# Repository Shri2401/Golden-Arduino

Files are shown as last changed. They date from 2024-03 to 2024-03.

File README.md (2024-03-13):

# Golden-Arduino
## Aim:
The project targets the creation of a standalone 4-layer instrument droid(Arduino base) focusing on:

- Utilizing a 328 microcontroller and data acquisition system.
- Prioritizing non-compatibility with Arduino Uno R3.
- Ensuring access to essential pins for bootloading.
- Emphasizing proficiency in 4-layer design.
- Measuring and characterizing the output impedance of diverse voltage sources, including dynamic Thevenin resistance.
- Providing thorough documentation focusing on design, assembly, testing, and code development.

## POR (Plan of Record):
The Plan of Record (POR) outlines various features and requirements of the project, including:

- Incorporating a power plug for an external 5V AC to DC charger.
- Implementing a voltage regulator for efficient operation of components.
- Including USB mini support for programming and powering the board.
- Integrating a power selector switch to choose between USB and external power supply.
- Utilizing a Low Drop-Out (LDO) regulator for stable 3.3V.
- Installing indicator LEDs for visual confirmation of power status.
- Implementing a power isolator switch and reset switch.
- Ensuring compatibility for bootloading and programming.
- Developing functionality to measure in-rush current and protect against static voltage damage.
- Providing extra headers for convenient ground connections.
- Planning test points for critical signals.
- Placing decoupling capacitors and implementing a copper poured ground plane.

## Risk Reduction Steps:
To mitigate risks associated with the project, various steps have been taken, including:

- Thorough research and validation of components.
- Prototyping and simulating critical sections of the board design.
- Performing comprehensive analysis of the board layout.
- Conducting in-depth testing of each feature.
- Implementing feedback mechanisms and standardizing signal lines.

## Demonstration Goals:
The demonstration goals include bootloading the Atmega 328, maintaining compatibility with standard header pin footprints, achieving noise levels lower than commercial boards, and more.

## Expectations of "Work":
Expectations include reliable power-up, efficient voltage regulation, accurate current measurement, smooth bootloading processes, and effective noise reduction measures.

## Significant Parts Used:
Significant parts used in the project include ATMEGA328, LDO (AMS1117), CH340g, Crystal Oscillators, DAC MCP4725, ADC ADS111x, and OP-AMP MCP6002.

##  Design:
Various visuals and diagrams are provided to illustrate the project's design, layout, and assembly process.
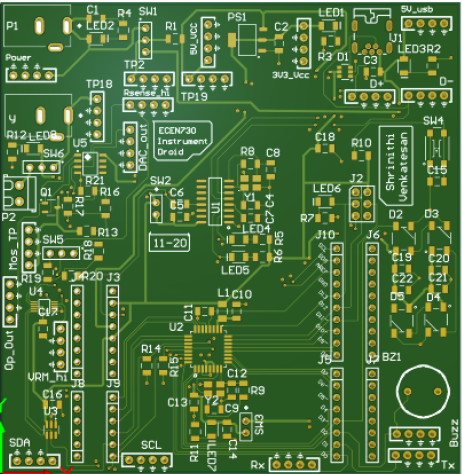
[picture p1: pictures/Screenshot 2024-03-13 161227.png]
Schematic

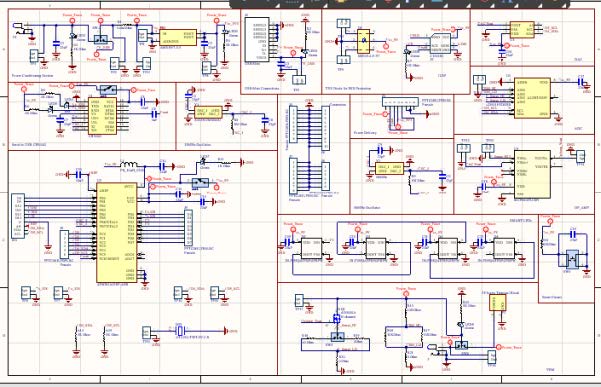
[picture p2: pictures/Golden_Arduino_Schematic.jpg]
Bare Board

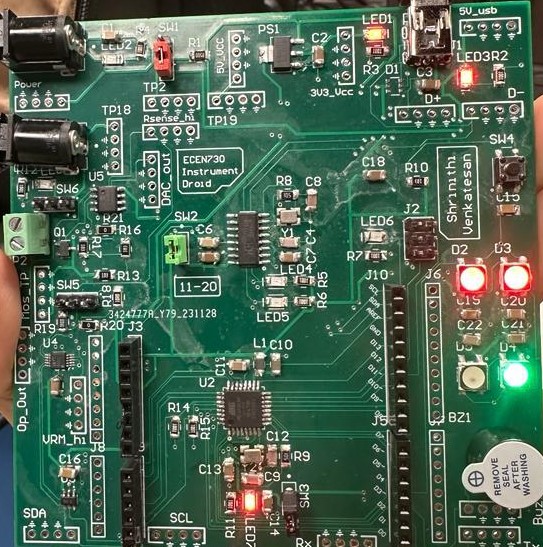
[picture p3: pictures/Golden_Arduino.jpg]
PCB


## Bring-Up Process Summary:
The bring-up process involved short testing of the bare board, precise component placement, soldering, testing, bootloading, and code execution.

## Learning Outcomes
Through the process of developing the circuit design and implementing strategic routing techniques, several valuable learning outcomes have been achieved:

1. Thorough Circuit Design: By deeply understanding and incorporating insights from available references, this project has emphasized the importance of meticulous circuit design. Prioritizing best design practices and optimizing layout have been essential steps in ensuring precision and reliability.

2. Signal Integrity Management: Employing strategic routing techniques and grounding practices has enabled the mitigation of potential signal integrity issues. Understanding the impact of layout and routing on signal quality has been crucial in optimizing performance.

3. Noise Resistance Improvement: Implementing best routing techniques and measures has led to better noise resistance compared to previous designs. By carefully considering the placement of components and utilizing techniques such as ferrite beads, noise interference has been minimized, resulting in improved overall performance.

4. Anticipating Expected Outcomes: Learning to anticipate the expected outcome based on design decisions and implementation choices has been a central aspect of this project. Understanding the role of each component and technique in achieving specific project goals has been essential in maintaining a systematic approach to circuit design and testing.

In conclusion, by incorporating these best practices and maintaining a systematic approach to circuit design and testing, the reliability and success of future projects can be greatly enhanced. Learning from both successes and challenges encountered during this project will contribute to further improvements and best implementations in future endeavors.

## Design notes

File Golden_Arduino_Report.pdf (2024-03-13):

ECEN 4730-5730-001 | Practical PCB Design Manufacture | Fall 2023
| Board4 Report
| Shrinithi Venkatesan

Aim:

The project targets a standalone 4-layer instrument droid for graduate students, featuring a 328 microcontroller and data acquisition system. It prioritizes non-compatibility with Arduino Uno R3 but ensures access to essential pins for bootloading. Emphasizing 4-layer design proficiency, the instrument measures and characterizes the output impedance of diverse voltage sources, including dynamic Thevenin resistance. Underpinned by insights from Lab 21, the solderless breadboard version, the process involves meticulous assembly, bootloading, and rigorous testing. Thorough documentation focuses on design, assembly, testing, and code development, enhancing the graduate educational experience in board design and microcontroller programming.

POR:

1. Incorporate a power plug for an external 5V AC to DC charger to power the board.
2. Implement a voltage regulator to convert 5V to 3.3V for efficient operation of components.
3. Include USB mini support for programming and powering the board.
4. Integrate a power selector switch to choose between USB and the 5V external power supply.
5. Utilize a Low Drop-Out (LDO) regulator to convert 5V to stable 3.3V.
6. Install indicator LEDs for visual confirmation of 5V and 3.3V power status.
7. Implement a power isolator switch to disconnect power to the microcontroller and CH340 chip.
8. Include a reset switch to initiate a reset of the microcontroller in case of undesired behavior.
9. Ensure In-Circuit Serial Programming (ICSP) compatibility for bootloading and programming the microcontroller.
10. Develop functionality to measure in-rush current during board startup.
11. Add Transient Voltage Suppression (TVS) chip to protect against static voltage damage.
12. Provide extra headers for convenient ground connections for sensors or other peripherals.
13. Plan test points for critical signals:
5V input
3.3V input
In-rush current measurement USB D+ and D-USB VBUS
Microcontroller RX and TX
Microcontroller SDA and SCL
14. Place decoupling capacitors in proximity to all ICs to reduce switching noise.

15. Implement a copper poured ground plane for effective signal return and noise reduction.
16. Implement an ADC to accurately measure the differential voltage between the sense resistor and the VRM.
17. Utilize the DAC output to drive the MOSFET through an Op-Amp, establishing a current source system.
18. Establish connections for smart LEDs and a buzzer to the digital pins of the ATmega328.

Risk Reduction Steps:

1. Thoroughly research and validate the chosen components for reliability and compatibility.
2. Prototype and simulate critical sections of the board design to identify and mitigate potential issues.
3. Perform a comprehensive analysis of the board layout to ensure proper signal integrity.
4. Conduct in-depth testing of each feature to validate its functionality and performance.
5. Implement feedback mechanisms to monitor and address potential problems during the testing phase.
6. Standardizing signal lines to 6 mils width and power lines to 20 mils width is a sound practice. This design decision simplifies the detection of signal and power nets, reducing the risk of misconnection or interference.
7. Keeping board size under 3.9” to ensure it sticks to standards.
8. Adhering to established best practices by using as many ground VIAs to ensure there’s no noise due to return currents in the ground plane. Placing decoupling capacitors closer to IC.
9. By placing test points and appropriately labeling them, you mitigate the risk of confusion during testing and debugging. This practice ensures that you can easily access critical points for measurement and verification.
10. Using switches at each stage for isolation and debugging purposes is a proactive measure to minimize risks. These switches allow you to control and isolate specific sections of the circuit, making it easier to identify and address issues without affecting the entire system.

Demonstration Goals:

1. Bootload the Atmega 328 to turn it into an Arduino.
2. Run the Arduino IDE and execute a standard sketch on the board.
3. Maintain compatibility with standard header pin footprints for shields.
4. Achieve noise levels 20% to 50% of a commercial board under identical conditions.
5. Ensure near-field emissions are less than 10% of a commercial Arduino board.
6. Optionally, add test points for digital buses to observe actual bus traffic.
7. Optionally, measure in-rush current and steady-state current with a series resistor for current sensing.

Expectations of what it is to “work”:

1. The board should reliably power up from both USB and a 5V external supply, ensuring consistent and stable operation.

2. The power indicator LED must promptly illuminate upon the application of power, providing a clear visual cue.
3. The voltage regulator should consistently and efficiently convert the 5V input to a stable and accurate 3.3V output.
4. The board should accurately measure the current flowing through one of the LEDs, providing a reliable metric for analysis.
5. SPI communication must function reliably to facilitate successful bootloading processes.
6. The board, configured as a Golden Arduino, should seamlessly execute any standard Arduino sketch, ensuring broad compatibility.
7. Indicator switches and lights should respond promptly to user inputs, enhancing the user interface and feedback mechanisms.
8. The reset signal should effectively reset the ATmega328, contributing to the stability of the microcontroller.
9. Bootloading processes should be smooth and compatible with various Arduino programmers, ensuring versatility in development environments.
10. Inrush current measurement, conducted using the scope, should provide accurate and meaningful results, allowing for comprehensive analysis.
11. The Low Drop-Out (LDO) regulator should consistently provide a steady 3.3V output without oscillations or instability.
12. Implemented design measures should result in a noticeable reduction in near-field emissions, contributing to electromagnetic compatibility.
13. Observing RX and TX waveforms during code loading should be clear and consistent, allowing for effective monitoring and analysis.
14. The board should demonstrate noise levels 20% to 50% lower than those observed in commercial Arduino boards, showcasing effective noise reduction measures.
15. The DAC ensures the accurate generation of voltage and waveform in accordance with the programmed code.
16. The instrument droid is equipped to conduct measurements, utilizing any external power source connected to the board's venin voltage and resistance.
17. The reset signal performs as anticipated, effectively resetting the ATmega328 when triggered

Significant Parts used:

1. ATMEGA328- https://www.microchip.com/en-us/product/atmega328p
2. LDO - AMS1117 - http://www.advanced-monolithic.com/pdf/ds1117.pdf
3. CH340g - 74AHC14
-https://cdn.sparkfun.com/datasheets/Dev/Arduino/Other/CH340DS1.PDF
4. Crystal Oscillators - 16,12Mhz
5. DAC MCP4725 https://ww1.microchip.com/downloads/en/devicedoc/22039d.pdf
6. ADC ADS111x https://www.ti.com/lit/ds/symlink/ads1114.pdf
7. OP-AMP MCP6002 https://www.microchip.com/en-us/product/mcp6002

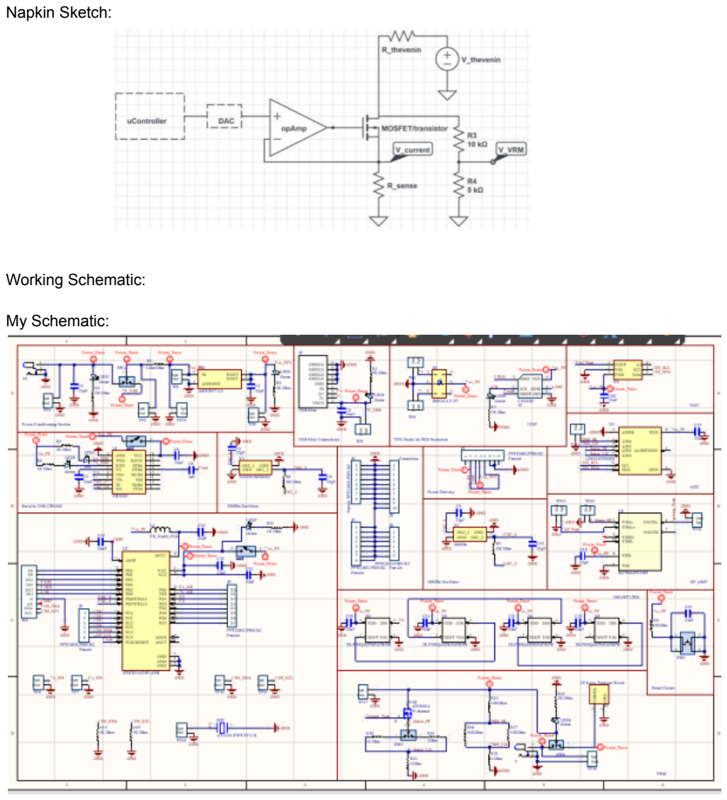
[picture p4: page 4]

Napkin Sketch:

Working Schematic:

My Schematic:

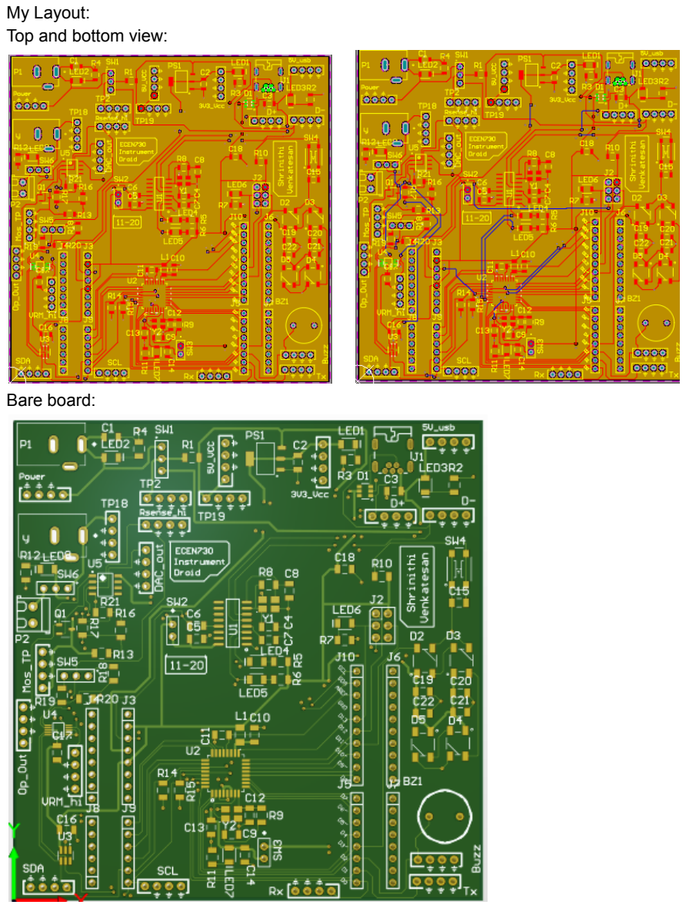
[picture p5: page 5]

My Layout:
Top and bottom view:

Bare board:

Assembled Board:

Power on design
Power plug and CH340

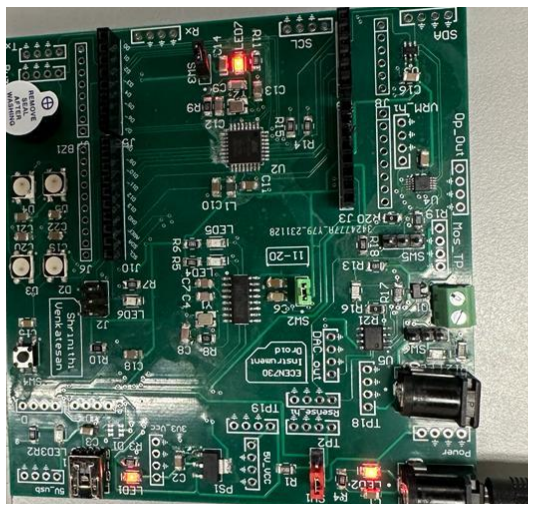
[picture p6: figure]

Bring-up Process Summary:

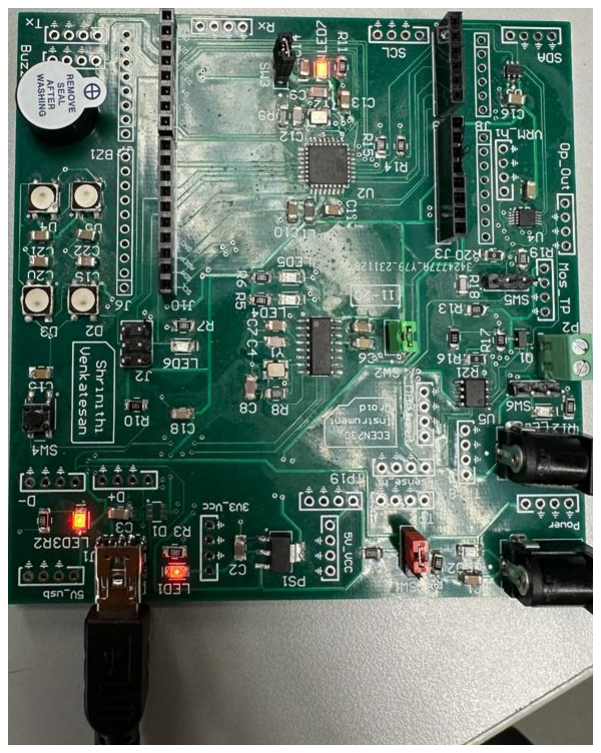
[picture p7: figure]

1. Conducted a short test on the bare board to verify the integrity of all connections and ensure proper functionality.
2. Placed all components, utilizing 1206 components, and ensured precise positioning before soldering.
3. Soldered the components with precision, followed by another round of short testing to identify and rectify any accidental shorts caused during soldering.Detected a short and tried to hard correct it by scratching out the trace, yet not successful.
4. 5V and LDO output was proper and verified.
5. Attempted to boot-load the controller using a commercial Arduino by just soldering the required components for that.
6. After that the blink code was dumped to verify communication with the controller working as expected.

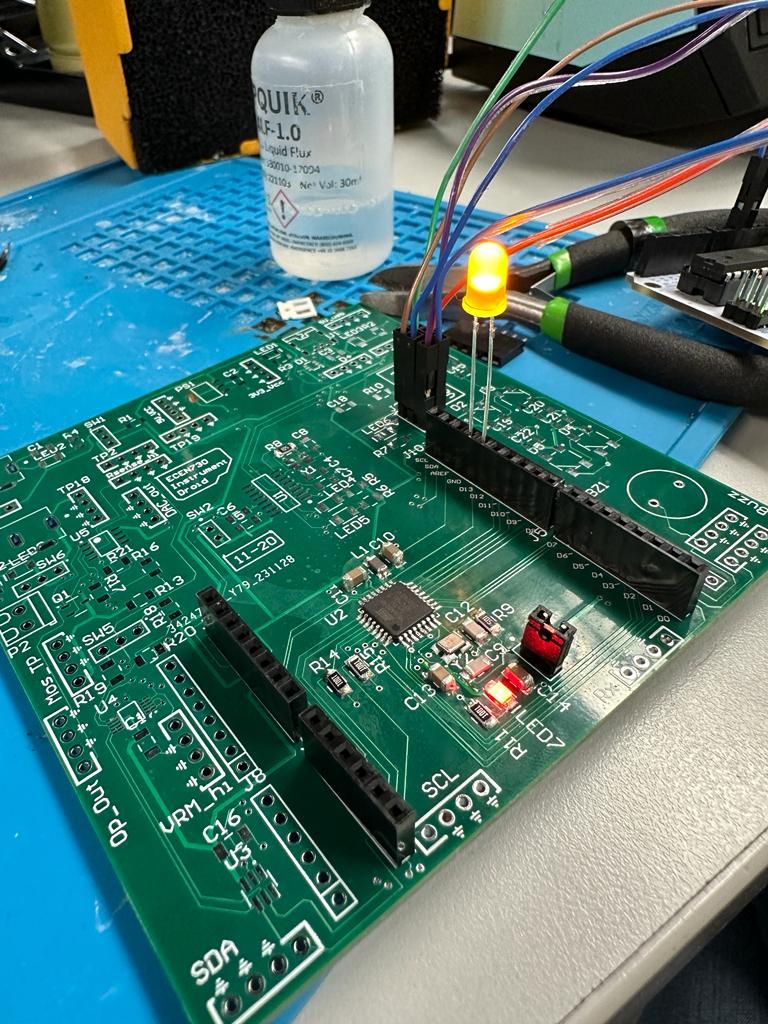
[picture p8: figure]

Measurements and Analysis:

Power rail outputs:

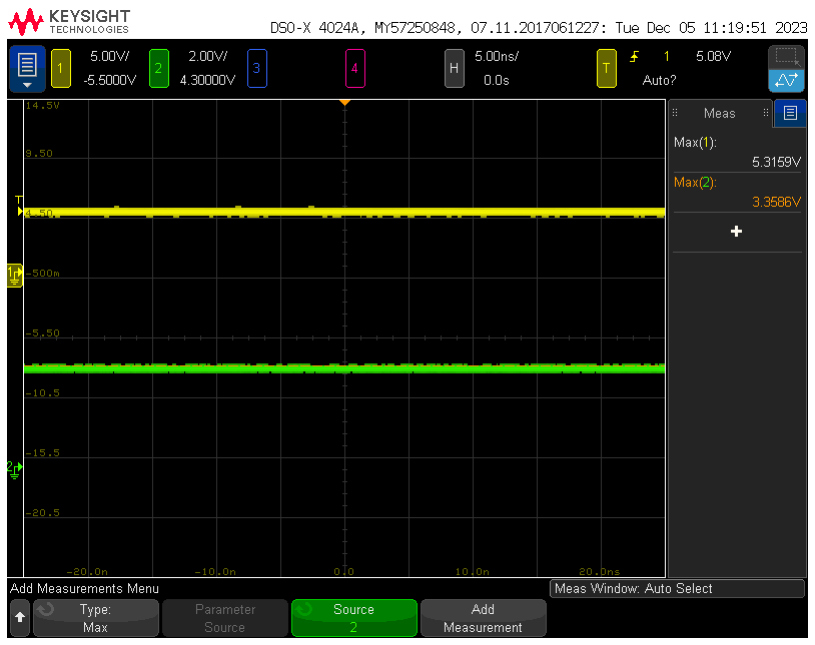
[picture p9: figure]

The observed voltages align closely with the expected values, with 5.3V and 3.3V measured at the 5V and 3.3V test points, respectively. The corresponding LEDs for both voltage rails have illuminated, indicating that the power supply and voltage regulation systems are functioning as intended.

The oscilloscope channel readings further validate the stability of the voltage rails. Channel 1 (Yellow) displays a consistent 3.3V, confirming the proper operation of the 3.3V rail. Similarly, Channel 2 (Green) shows a steady 5V, validating the performance of the 5V rail.

These results demonstrate the successful power supply and voltage regulation aspects of the board, providing a solid foundation for further testing and functionality verification.

Oscillator Outputs:

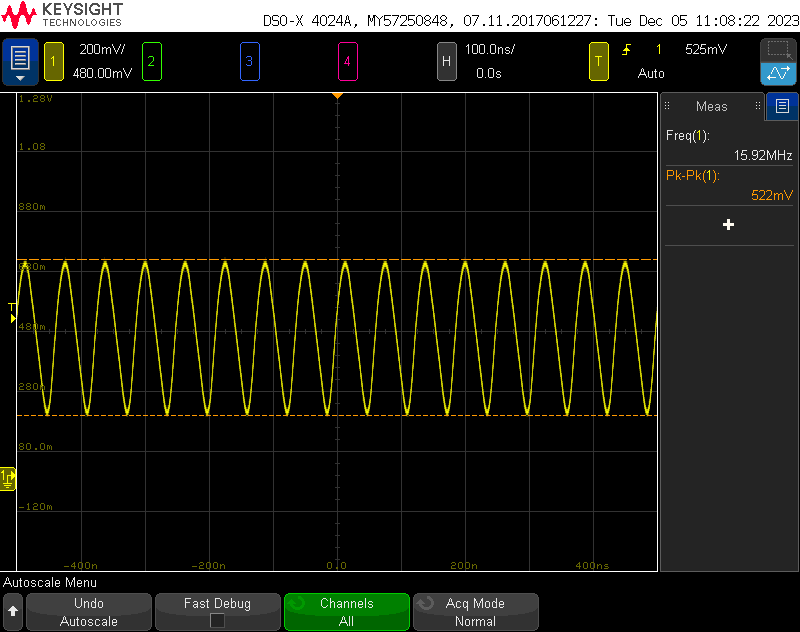
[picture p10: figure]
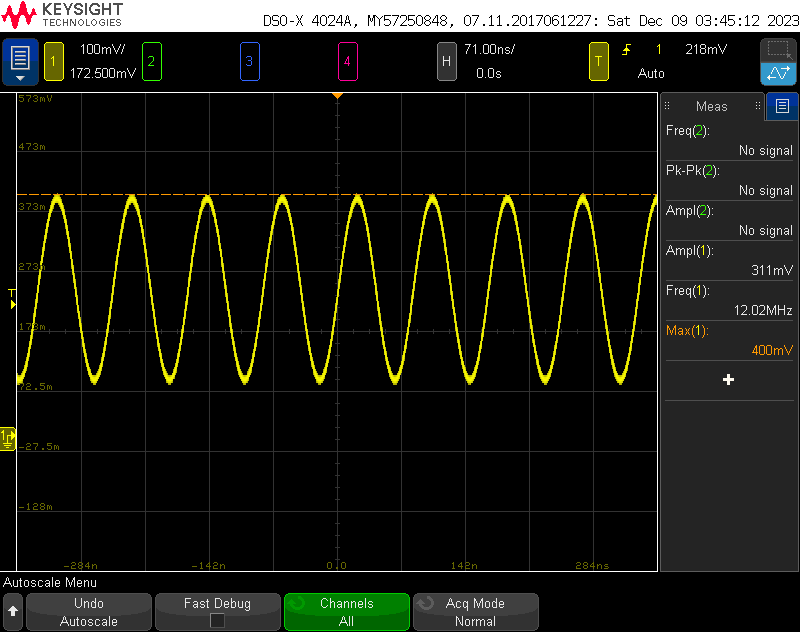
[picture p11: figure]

12Mhz from Y1 | 16Mhz from Y1

The presence of a 16MHz clock signal for the microcontroller indicates that the ATmega328 or a similar microcontroller is operating at the expected frequency. The presence of a 12MHz clock signal for the CH340G indicates that the USB-to-serial converter is functioning with the expected clock frequency.

Data Signals: D+ and D-:

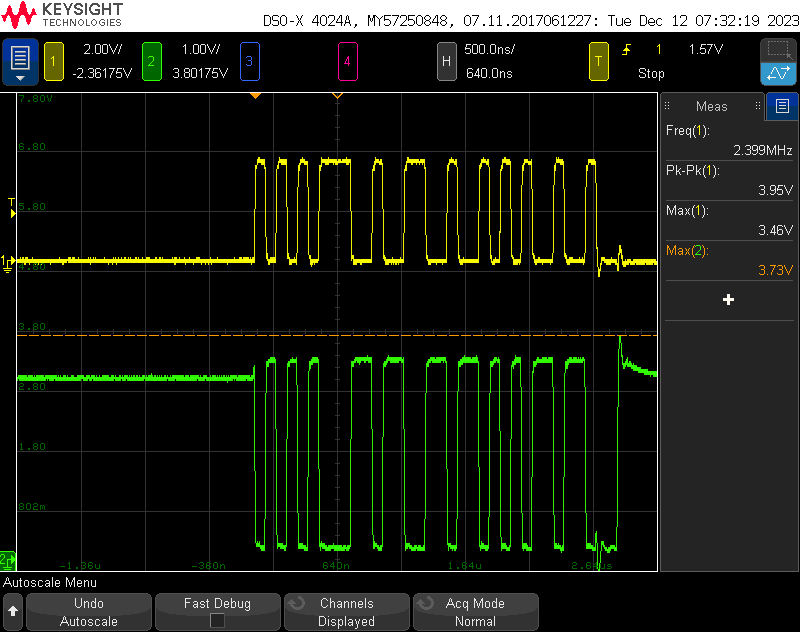
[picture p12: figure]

The presence of both the D+ (yellow trace) and D- (green trace) signals, specifically when the board is powered by a mini-USB cable and a USB port is detected, verifies the correct connection and functionality of the CH340G chip. These differential signals carry the data and inverted data signals, and their successful observation under the specified conditions indicates the proper operation of the USB communication interface.

The detection of a USB port serves as a positive confirmation that the D+ and D- signals are correctly connected. This validation is crucial for ensuring the reliable communication and functionality of the USB interface on the board.

Rx and Tx signals:

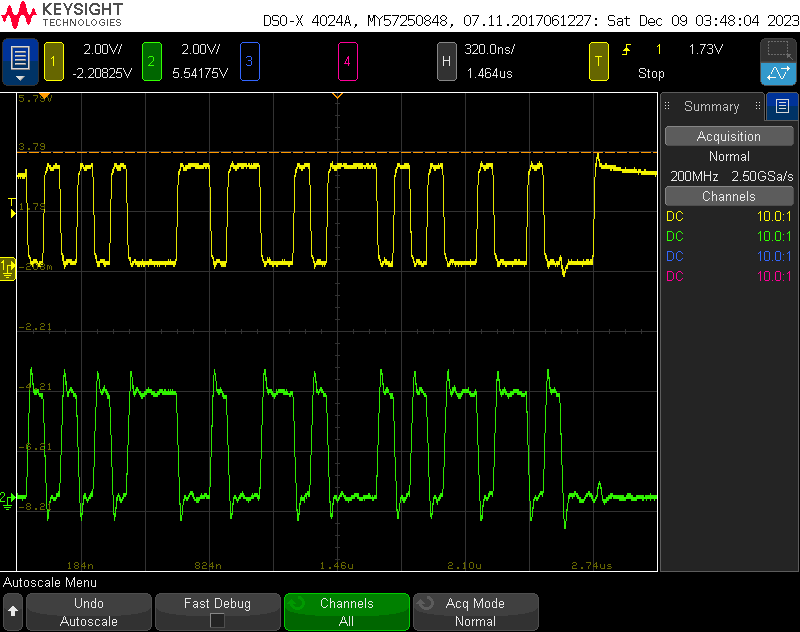
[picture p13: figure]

The observed UART Rx (yellow trace) and UART Tx (green trace) waveforms confirm the interaction between the ATmega328 microcontroller and the CH340G during the code uploading process through USB. The blinking of the Rx and Tx LEDs during code upload indicates the successful communication between the microcontroller and the USB interface.

The triggering of the signals on the falling edge, as mentioned, aligns with UART communication standards where a 0 bit is used as the start bit. This behavior is consistent with proper UART communication protocols.

These results validate the functional interaction between the microcontroller and the USB interface, ensuring the successful upload of code to the ATmega328. The observed waveforms provide valuable insights into the communication dynamics and help verify the integrity of the UART interface on the board.

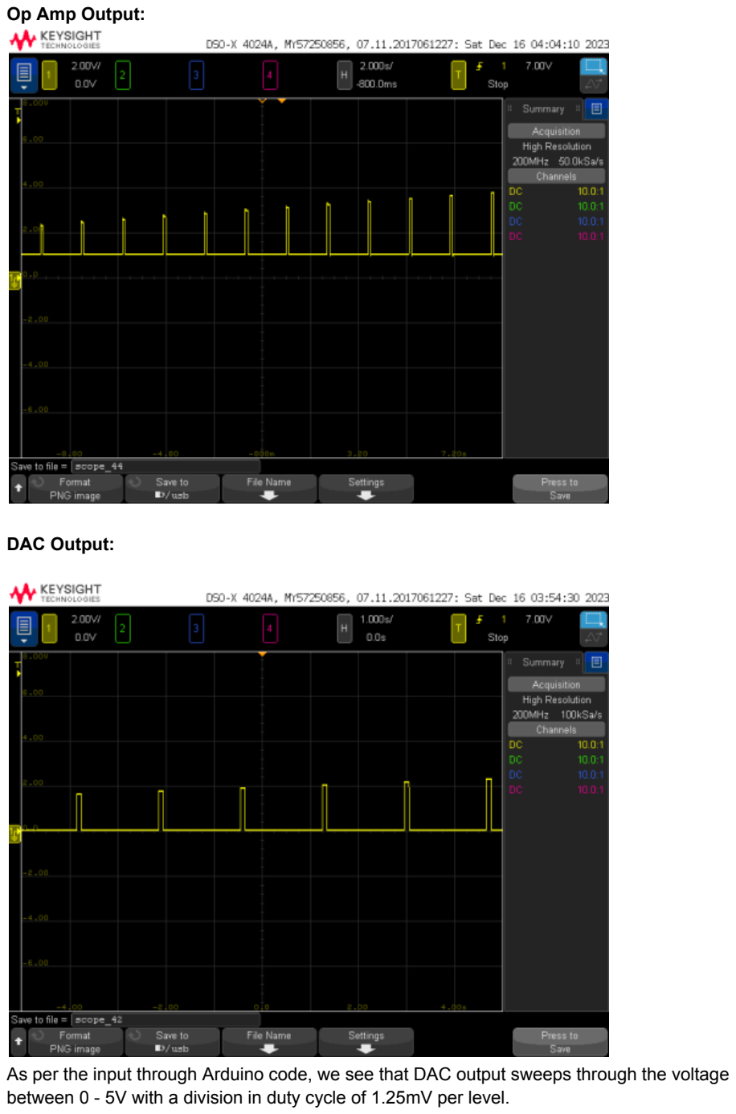
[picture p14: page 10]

Op Amp Output:

DAC Output:

As per the input through Arduino code, we see that DAC output sweeps through the voltage between 0 - 5V with a division in duty cycle of 1.25mV per level.

Power source characteristics:
As a known source, we apply an input of 5V, 9V and 2A through the source and plot our respective outputs through the circuit. We observe expected outputs when using 10ohm sense resistor value.

9V 2A
Index, current in mA, V_thevenin, V_loaded, R_thevenin

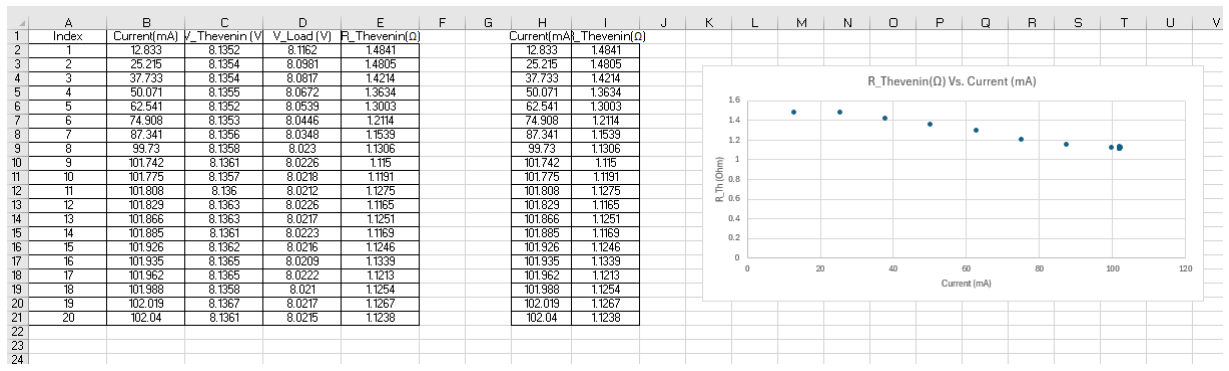
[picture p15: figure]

The yellow trace here is the Rth plot

5V 2A
Index, current in mA, V_thevenin, V_loaded, R_thevenin

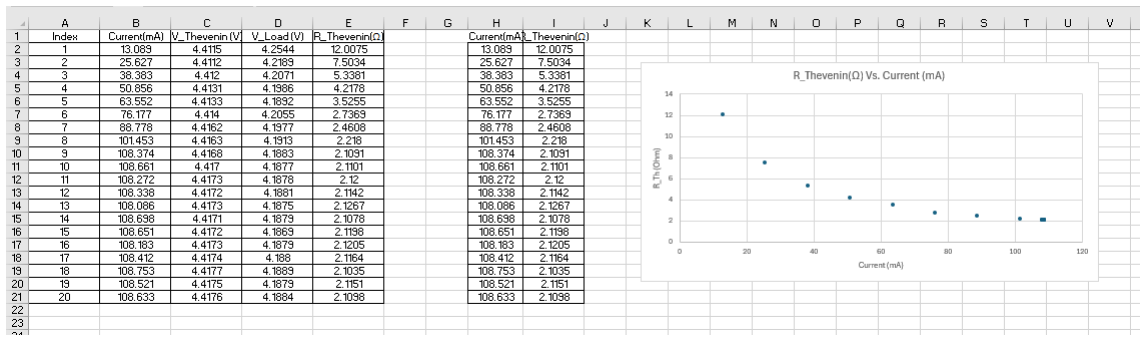
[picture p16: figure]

Here, I have compared the values between Current(blue) vs Rth(yellow)

5V 1A (bench power gen)
Through the function generator we provide input of 5V 1A and observe the following output as expected values. We first experimented with unknown values of VRM using a variety of sense resistor values from 1 Ohm and finally used 10 Ohm to observe the following output.

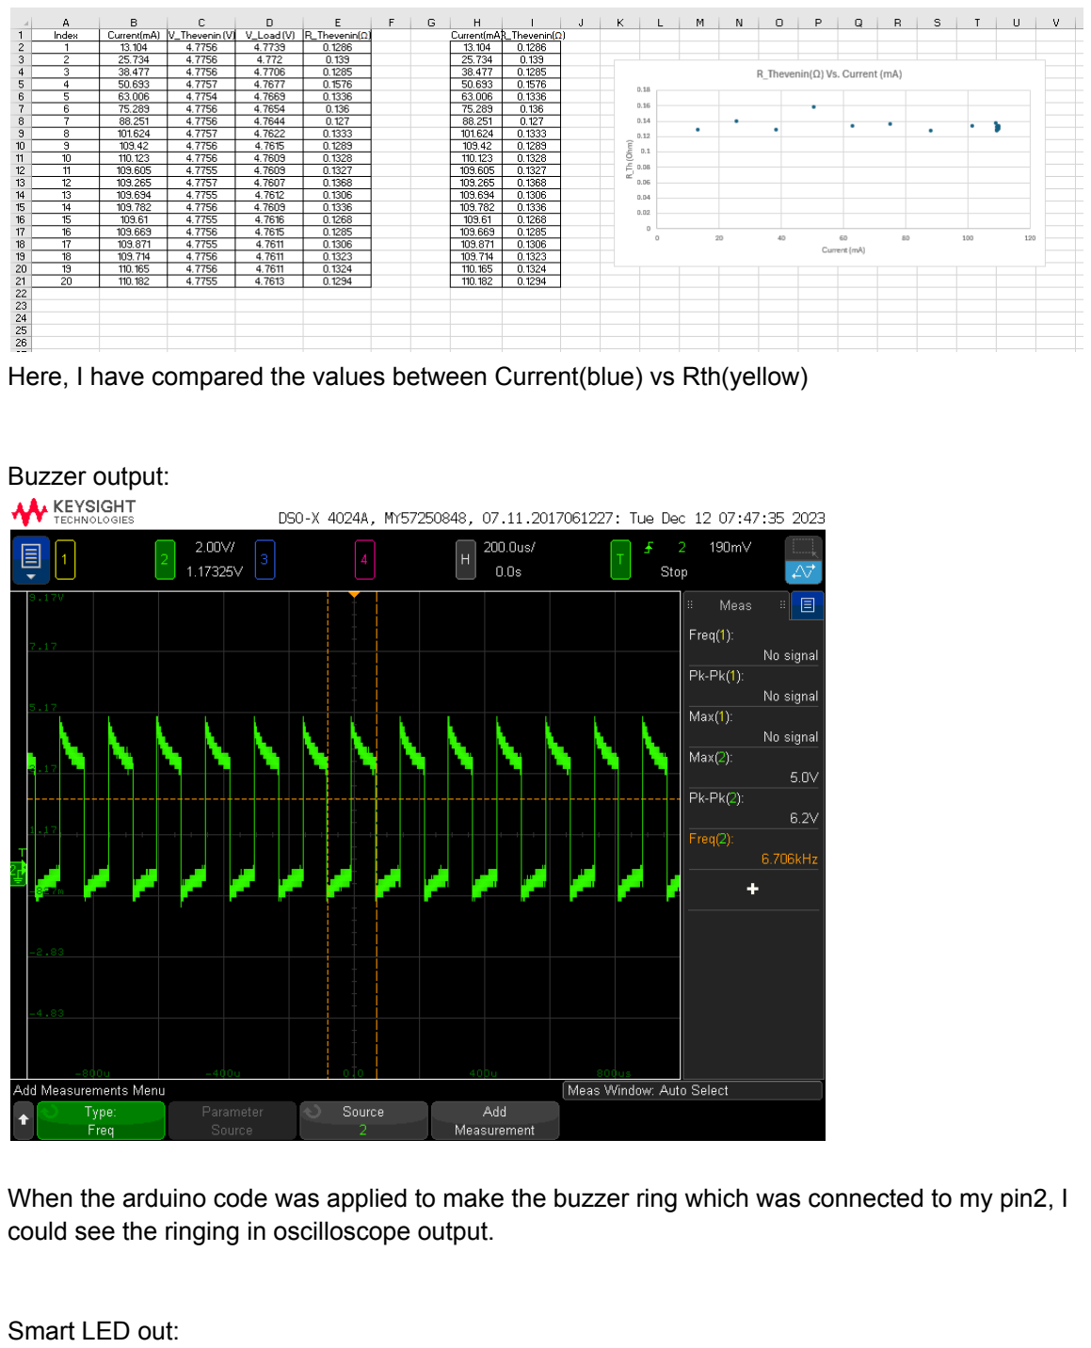
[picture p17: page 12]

Here, I have compared the values between Current(blue) vs Rth(yellow)

Buzzer output:

When the arduino code was applied to make the buzzer ring which was connected to my pin2, I could see the ringing in oscilloscope output.

Smart LED out:

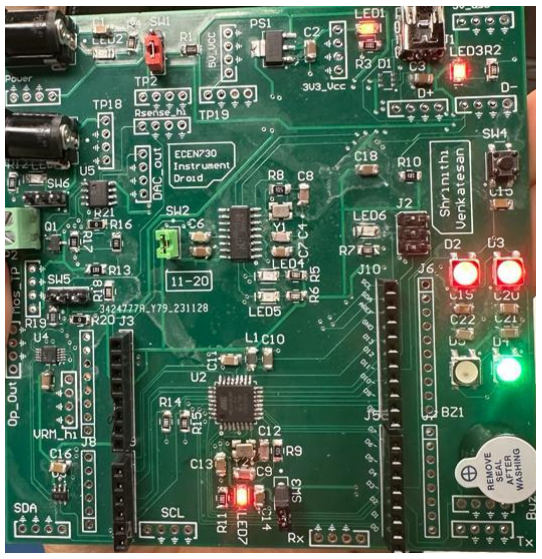
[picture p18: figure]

When arduino code was applied to smart leds connected to onboard pin3, I could make use of the example code to test and verify the working of my LEDs.

Analysis of my project:

THROUGH CORRECTING ERRORS FROM MY DESIGN OF LAST BOARD, I COULD INCORPORATE BETTER DESIGN AND MY BOARD 4 WORKED WITH VERIFYING MY BOARD 3 PARAMETERS AS WELL.

What worked?

1. The board reliably powers up seamlessly from both USB and a 5V external supply, ensuring consistent and stable operation.
2. The power indicator LED promptly illuminates upon the application of power, providing a clear visual cue for successful power activation.
3. The voltage regulator consistently and efficiently converts the 5V input to a stable and accurate 3.3V output, ensuring reliable power regulation.
4. Accurate measurement of the current flowing through one of the LEDs is achieved, providing a reliable metric for in-depth analysis.
5. SPI communication functions reliably, facilitating successful bootloading processes and ensuring smooth communication protocols.
6. Configured as an Arduino, the board seamlessly executes any standard Arduino sketch, demonstrating broad compatibility and versatility.
7. Indicator switches and lights respond promptly to user inputs, enhancing the user interface and providing effective feedback mechanisms.
8. The reset signal effectively resets the ATmega328, contributing to the stability and reliable operation of the microcontroller.

9. Bootloading processes are smooth and compatible with various Arduino programmers, ensuring flexibility in development environments.
10. Inrush current measurement, conducted using the scope, provides accurate and meaningful results, enabling comprehensive analysis of power dynamics.
11. Observing RX and TX waveforms during code loading is clear and consistent, allowing for effective monitoring and analysis of communication signals.
12. The CH340 USB-to-serial converter successfully established communication, detected the COM port.
13. Transmit and Receive LEDs indicated seamless communication activity.
14. The reset circuit reliably initializes the system, contributing to stability.
15. Analog-to-Digital and Digital-to-Analog converters provided precise signal conversion.
16. The Op Amp and Mosfet combinational circuit functioned effectively.
17. Thermal resistance (Rth) was accurately calculated using the Voltage Regulator Module (VRM).
18. The LEDs and BUzzer worked as per the expected code functionality.

What did not work and what to correct for the future?
1. Fortunately by correcting my errors of carefully placing the oscillators and other components, I was able to get my board working at first shot this time.
2. I had, although missed, placed the decoupling capacitor of one component a little far from the IC, but it didn't bother the circuit as the component did not involve in measurements.
3. Initially, I had no reading through DAC and I had replaced the component to make it work and I anticipate it might be the component issue. Also, I had to figure out the address of the DAC carefully by trial and error, which took a little anticipation to know what is expected. Rule 9 helped here as we already did a breadboard version of this board successfully

Learning Outcomes:

1. Develop the circuit design by thoroughly understanding and incorporating insights from available references, adhering to best design practices. Prioritize a meticulous layout to optimize performance. Perform Clock and Data Recovery (CDR) analysis before proceeding to board fabrication to ensure precision and reliability.
2. Employ strategic routing techniques and grounding practices to mitigate potential signal integrity issues.
3. Implement best routing techniques and measures to ensure I get better noise resistance compared to this design.
4. Understand the importance of components, like where to use ferrite beads over power rails and when not to. Always, a main rule, anticipate the expected outcome.

In conclusion, by implementing these best practices and maintaining a systematic approach to circuit design and testing, you can enhance the reliability and success of your projects. Learning from past experiences, both successes and challenges, will contribute to my further best implementations.

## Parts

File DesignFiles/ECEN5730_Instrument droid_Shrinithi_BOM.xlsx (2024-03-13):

Comment | Description | Designator | Footprint | LibRef | Quantity | LCSC Part#
10x Probe TP | Test Point 300 mil centers | 3V3_Vcc | TP10x_Probe | TP_10x_Probe | 1
10x Probe TP | Test Point 300 mil centers | 5V_usb | TP10x_Probe | TP_10x_Probe | 1
10x Probe TP | Test Point 300 mil centers | 5V_VCC | TP10x_Probe | TP_10x_Probe | 1
10x Probe TP | Test Point 300 mil centers | Buzz | TP10x_Probe | TP_10x_Probe | 1
AT-1224-TWT-5V-2-R | Buzzers Transducer, Externally Driven Electromechanical/Magnetic 5 V 40mA 2.4kHz 87dB @ 5V, 10cm Through Hole PC Pins | BZ1 | BUZZER- TH | BUZZER_1 | 1
22uF | 22uF ±10% 25V X5R 1206 Multilayer Ceramic Capacitors MLCC - SMD/SMT RoHS | C1 | 1206_Passive_Capacitor | C_22uF_1206 | 1 | C12891
22uF | 22uF ±10% 25V X5R 1206 Multilayer Ceramic Capacitors MLCC - SMD/SMT RoHS | C2 | 1206_Passive_Capacitor | C_22uF_1206 | 1 | C12891
22uF | 22uF ±10% 25V X5R 1206 Multilayer Ceramic Capacitors MLCC - SMD/SMT RoHS | C3 | 1206_Passive_Capacitor | C_22uF_1206 | 1 | C12891
22pF | 22pF ±5% 1kV C0G 1206 Multilayer Ceramic Capacitors MLCC - SMD/SMT RoHS | C4 | 1206_Passive_Capacitor | C_22pF_1206 | 1 | C107174
22uF | 22uF ±10% 25V X5R 1206 Multilayer Ceramic Capacitors MLCC - SMD/SMT RoHS | C5 | 1206_Passive_Capacitor | C_22uF_1206 | 1 | C12891
1uF | MULTILAYER CERAMIC CAPACITORS MLCC - SMD/SMT 1UF 50V 1206 ROHS | C6 | 1206_Passive_Capacitor | C_1uF_1206 | 1 | C1848
22uF | 22uF ±10% 25V X5R 1206 Multilayer Ceramic Capacitors MLCC - SMD/SMT RoHS | C7 | 1206_Passive_Capacitor | C_22uF_1206 | 1 | C12891
22pF | 22pF ±5% 1kV C0G 1206 Multilayer Ceramic Capacitors MLCC - SMD/SMT RoHS | C8 | 1206_Passive_Capacitor | C_22pF_1206 | 1 | C107174
22pF | 22pF ±5% 1kV C0G 1206 Multilayer Ceramic Capacitors MLCC - SMD/SMT RoHS | C9 | 1206_Passive_Capacitor | C_22pF_1206 | 1 | C107174
22uF | 22uF ±10% 25V X5R 1206 Multilayer Ceramic Capacitors MLCC - SMD/SMT RoHS | C10 | 1206_Passive_Capacitor | C_22uF_1206 | 1 | C12891
10uF | 10uF ±10% 50V X5R 1206 Multilayer Ceramic Capacitors MLCC - SMD/SMT RoHS | C11 | 1206_Passive_Capacitor | C_10uF_1206 | 1 | C13585
22pF | 22pF ±5% 1kV C0G 1206 Multilayer Ceramic Capacitors MLCC - SMD/SMT RoHS | C12 | 1206_Passive_Capacitor | C_22pF_1206 | 1 | C107174
22uF | 22uF ±10% 25V X5R 1206 Multilayer Ceramic Capacitors MLCC - SMD/SMT RoHS | C13 | 1206_Passive_Capacitor | C_22uF_1206 | 1 | C12891
22uF | 22uF ±10% 25V X5R 1206 Multilayer Ceramic Capacitors MLCC - SMD/SMT RoHS | C14 | 1206_Passive_Capacitor | C_22uF_1206 | 1 | C12891
47nF | 47nF ±5% 50V C0G 1206 Multilayer Ceramic Capacitors MLCC - SMD/SMT RoHS | C15 | 1206_Passive_Capacitor | C_47nF_1206 | 1 | C21812
22uF | 22uF ±10% 25V X5R 1206 Multilayer Ceramic Capacitors MLCC - SMD/SMT RoHS | C16 | 1206_Passive_Capacitor | C_22uF_1206 | 1 | C12891
22uF | 22uF ±10% 25V X5R 1206 Multilayer Ceramic Capacitors MLCC - SMD/SMT RoHS | C17 | 1206_Passive_Capacitor | C_22uF_1206 | 1 | C12891
22uF | 22uF ±10% 25V X5R 1206 Multilayer Ceramic Capacitors MLCC - SMD/SMT RoHS | C18 | 1206_Passive_Capacitor | C_22uF_1206 | 1 | C12891
22uF | 22uF ±10% 25V X5R 1206 Multilayer Ceramic Capacitors MLCC - SMD/SMT RoHS | C19 | 1206_Passive_Capacitor | C_22uF_1206 | 1 | C12891
22uF | 22uF ±10% 25V X5R 1206 Multilayer Ceramic Capacitors MLCC - SMD/SMT RoHS | C20 | 1206_Passive_Capacitor | C_22uF_1206 | 1 | C12891
22uF | 22uF ±10% 25V X5R 1206 Multilayer Ceramic Capacitors MLCC - SMD/SMT RoHS | C21 | 1206_Passive_Capacitor | C_22uF_1206 | 1 | C12891
22uF | 22uF ±10% 25V X5R 1206 Multilayer Ceramic Capacitors MLCC - SMD/SMT RoHS | C22 | 1206_Passive_Capacitor | C_22uF_1206 | 1 | C12891
SRV05-4-P-T7 | TVS SOT-23-6 ROHS | D1 | TVS | D_TVS_Diode | 1 | C85364
IN-PI55QATPRPGPBPW | LIGHT EMITTING DIODES (LED) RGB 620~630NM RED, 520~530NM GREEN, 465~475NM BLUE 600MCD@16MARED,1200MCD@16MAGREEN,300MCD@16MABLUE TOP VIEW SMD-4 ROHS | D2 | SERIAL_LED - duplicate | LED_Smart | 1 | C2843785
IN-PI55QATPRPGPBPW | LIGHT EMITTING DIODES (LED) RGB 620~630NM RED, 520~530NM GREEN, 465~475NM BLUE 600MCD@16MARED,1200MCD@16MAGREEN,300MCD@16MABLUE TOP VIEW SMD-4 ROHS | D3 | SERIAL_LED - duplicate | LED_Smart | 1 | C2843785
IN-PI55QATPRPGPBPW | LIGHT EMITTING DIODES (LED) RGB 620~630NM RED, 520~530NM GREEN, 465~475NM BLUE 600MCD@16MARED,1200MCD@16MAGREEN,300MCD@16MABLUE TOP VIEW SMD-4 ROHS | D4 | SERIAL_LED - duplicate | LED_Smart | 1 | C2843785
IN-PI55QATPRPGPBPW | LIGHT EMITTING DIODES (LED) RGB 620~630NM RED, 520~530NM GREEN, 465~475NM BLUE 600MCD@16MARED,1200MCD@16MAGREEN,300MCD@16MABLUE TOP VIEW SMD-4 ROHS | D5 | SERIAL_LED - duplicate | LED_Smart | 1 | C2843785
10x Probe TP | Test Point 300 mil centers | D- | TP10x_Probe | TP_10x_Probe | 1
10x Probe TP | Test Point 300 mil centers | D+ | TP10x_Probe | TP_10x_Probe | 1
10x Probe TP | Test Point 300 mil centers | DAC_out | TP10x_Probe | TP_10x_Probe | 1
USB Mini | Through Hole USB Connectors RoHS | J1 | USB_MINI_B | J_USB_B_Mini | 1 | C46398
NRPN032PAEN-RC | Connector Header Through Hole 6 position 0.079" (2.00mm) | J2 | ICSP | J_ICSP | 1 | C124384
PPTC081LFBN-RC | 8 Position Header Connector 0.100" (2.54mm) Through Hole Tin | J3 | 8_PIN_100MIL - Female | JF_8_PIN_FEMALE | 1 | C27438
PPTC081LFBN-RC | 8 Position Header Connector 0.100" (2.54mm) Through Hole Tin | J4 | 8_PIN_100MIL - Female | JF_8_PIN_FEMALE | 1 | C27438
PPTC081LFBN-RC | 8 Position Header Connector 0.100" (2.54mm) Through Hole Tin | J5 | 8_PIN_ARD-DIG_100MIL | JF_8_PIN_FEMA_ARD-Dig | 1 | C27438
PPTC101LFBN-RC | 10 Position Header Connector 0.100" (2.54mm) Through Hole Tin | J6 | 10_PIN_100MIL - Female | JF_10_PIN_FEMALE_ | 1 | C225507
PPTC081LFBN-RC | 8 Position Header Connector 0.100" (2.54mm) Through Hole Tin | J7 | 8_PIN_100MIL - Female | JF_8_PIN_FEMALE | 1 | C27438
PPTC061LFBN-RC | 6 Position Header Connector 0.100" (2.54mm) Through Hole Tin | J8 | 6_PIN_100MIL -Female | JF_6_PIN_FEMALE | 1 | C40877
PPTC061LFBN-RC | 6 Position Header Connector 0.100" (2.54mm) Through Hole Tin | J9 | 6_PIN_100MIL -Female | JF_6_PIN_FEMALE | 1 | C40877
PPTC101LFBN-RC | 10 Position Header Connector 0.100" (2.54mm) Through Hole Tin | J10 | 10_PIN_ARDUINO_100MIL | JF_10_PIN_FEMA_ARDUINO | 1 | C225507
FB_10uH_1206 | 25mA 10uH ±10% 800mΩ 1206 Inductors (SMD) ROHS | L1 | AIML-1206_ABR-M | FB_10uH_1206 | 1 | C1051
Green | Green 513~528nm 1206 Light Emitting Diodes (LED) RoHS | LED1 | LED_1206 | LED_GREEN_1206 | 1 | C434439
Green | Green 513~528nm 1206 Light Emitting Diodes (LED) RoHS | LED2 | LED_1206 | LED_GREEN_1206 | 1 | C434439
Green | Green 513~528nm 1206 Light Emitting Diodes (LED) RoHS | LED3 | LED_1206 | LED_GREEN_1206 | 1 | C434439
Red | Red 621~631nm 1206 Light Emitting Diodes (LED) RoHS | LED4 | LED_1206 | LED_RED_1206 | 1 | C93133
Green | Green 513~528nm 1206 Light Emitting Diodes (LED) RoHS | LED5 | LED_1206 | LED_GREEN_1206 | 1 | C434439
Green | Green 513~528nm 1206 Light Emitting Diodes (LED) RoHS | LED6 | LED_1206 | LED_GREEN_1206 | 1 | C434439
Green | Green 513~528nm 1206 Light Emitting Diodes (LED) RoHS | LED7 | LED_1206 | LED_GREEN_1206 | 1 | C434439
Green | Green 513~528nm 1206 Light Emitting Diodes (LED) RoHS | LED8 | LED_1206 | LED_GREEN_1206 | 1 | C434439
10x Probe TP | Test Point 300 mil centers | Mos_TP | TP10x_Probe | TP_10x_Probe | 1
10x Probe TP | Test Point 300 mil centers | Op_Out | TP10x_Probe | TP_10x_Probe | 1
Power Jack | Power Barrel Connector Jack 2.10mm ID (0.083"), 5.50mm OD (0.217") Through Hole, Right Angle | P1 | Power_Jack | P_Power Jack | 1 | C136744
2P Screw Terminal Block | Green Straight pin 3.5mm pitch; P=3.5mm Screw terminal ROHS | P2 | P_Terminal block 3.5mm-pitch | P_Terminal block | 1 | C474892
10x Probe TP | Test Point 300 mil centers | Power | TP10x_Probe | TP_10x_Probe | 1
AMS1117-3.3 | LOW DROPOUT REGULATORS(LDO) POSITIVE FIXED 1.3V @ 800MA 15V 3.3V 1A SOT-223 ROHS | PS1 | LDO | PS_AMS_LDO_3v3 | 1 | C6186
AO3400A | MOSFET N Trench 30V 5.7A 1.5V @ 250uA 26.5 m? @ 5.7A,10V SOT-23-3L RoHS | Q1 | N-MOSFET | Q_Nch_MOSFET | 1 | C20917
500m | Resistors/Shunt 250mW 500mΩ ±800ppm/℃ ±5% 1206 Current Sense Resistors ROHS | R1 | 1206_Passive_Resitor | R_500mOhm_1206 | 1 | C247433
1k | CHIP RESISTOR - SURFACE MOUNT 1KOHMS ±1% 1/4W 1206 ROHS | R2 | 1206_Passive_Resitor | R_1K_1206 | 1 | C4410
1k | CHIP RESISTOR - SURFACE MOUNT 1KOHMS ±1% 1/4W 1206 ROHS | R3 | 1206_Passive_Resitor | R_1K_1206 | 1 | C4410
1k | CHIP RESISTOR - SURFACE MOUNT 1KOHMS ±1% 1/4W 1206 ROHS | R4 | 1206_Passive_Resitor | R_1K_1206 | 1 | C4410
1k | CHIP RESISTOR - SURFACE MOUNT 1KOHMS ±1% 1/4W 1206 ROHS | R5 | 1206_Passive_Resitor | R_1K_1206 | 1 | C4410
1k | CHIP RESISTOR - SURFACE MOUNT 1KOHMS ±1% 1/4W 1206 ROHS | R6 | 1206_Passive_Resitor | R_1K_1206 | 1 | C4410
1k | CHIP RESISTOR - SURFACE MOUNT 1KOHMS ±1% 1/4W 1206 ROHS | R7 | 1206_Passive_Resitor | R_1K_1206 | 1 | C4410
1M | CHIP RESISTOR - SURFACE MOUNT 1MOHMS ±1% 1/4W 1206 ROHS | R8 | 1206_Passive_Resitor | R_1M_1206 | 1 | C17927
1M | CHIP RESISTOR - SURFACE MOUNT 1MOHMS ±1% 1/4W 1206 ROHS | R9 | 1206_Passive_Resitor | R_1M_1206 | 1 | C17927
10k | 10 kOhms ±5% 0.25W, 1/4W Chip Resistor 1206 (3216 Metric) Automotive AEC-Q200 Thick Film | R10 | 1206_Passive_Resitor | R_10KOhm_1206 | 1 | C17902
1k | CHIP RESISTOR - SURFACE MOUNT 1KOHMS ±1% 1/4W 1206 ROHS | R11 | 1206_Passive_Resitor | R_1K_1206 | 1 | C4410
1k | CHIP RESISTOR - SURFACE MOUNT 1KOHMS ±1% 1/4W 1206 ROHS | R12 | 1206_Passive_Resitor | R_1K_1206 | 1 | C4410
10k | 10 kOhms ±5% 0.25W, 1/4W Chip Resistor 1206 (3216 Metric) Automotive AEC-Q200 Thick Film | R13 | 1206_Passive_Resitor | R_10KOhm_1206 | 1 | C17902
1k | CHIP RESISTOR - SURFACE MOUNT 1KOHMS ±1% 1/4W 1206 ROHS | R14 | 1206_Passive_Resitor | R_1K_1206 | 1 | C4410
1k | CHIP RESISTOR - SURFACE MOUNT 1KOHMS ±1% 1/4W 1206 ROHS | R15 | 1206_Passive_Resitor | R_1K_1206 | 1 | C4410
10k | 10 kOhms ±5% 0.25W, 1/4W Chip Resistor 1206 (3216 Metric) Automotive AEC-Q200 Thick Film | R16 | 1206_Passive_Resitor | R_10KOhm_1206 | 1 | C17902
10k | 10 kOhms ±5% 0.25W, 1/4W Chip Resistor 1206 (3216 Metric) Automotive AEC-Q200 Thick Film | R17 | 1206_Passive_Resitor | R_10KOhm_1206 | 1 | C17902
10 Ohm | CHIP RESISTOR - SURFACE MOUNT 0.1OHMS ±1% 1/4W 1206 ROHS | R18 | 1206_Passive_Resitor | R_10Ohm_1206 | 1 | C17903
1 Ohm | 1Ω ±5% 0.25W ±400ppm/℃ 1206 Chip Resistor - Surface Mount RoHS | R19 | 1206_Passive_Resitor | R_1Ohm_1206 | 1 | C1409
0 Ohm | CHIP RESISTOR - SURFACE MOUNT 0OHMS ±1% 1/4W 1206 ROHS | R20 | 1206_Passive_Resitor | R_0Ohm_1206 | 1 | C17888
0 Ohm | CHIP RESISTOR - SURFACE MOUNT 0OHMS ±1% 1/4W 1206 ROHS | R21 | 1206_Passive_Resitor | R_0Ohm_1206 | 1 | C17888
10x Probe TP | Test Point 300 mil centers | Rsense_hi | TP10x_Probe | TP_10x_Probe | 1
10x Probe TP | Test Point 300 mil centers | Rx | TP10x_Probe | TP_10x_Probe | 1
10x Probe TP | Test Point 300 mil centers | SCL | TP10x_Probe | TP_10x_Probe | 1
10x Probe TP | Test Point 300 mil centers | SDA | TP10x_Probe | TP_10x_Probe | 1
PREC003SAAN-RC | Connector Header Through Hole 3 position 0.100" (2.54mm) | SW1 | 3_PIN_100mil | SW_3Pin_100mil_Switch | 1 | C49257
SW_2Pin_100mil_Switch | 2Pin Header | SW2 | 2Pin-Header-Conn | SW_2Pin_100mil_Switch | 1 | C124375
SW_2Pin_100mil_Switch | 2Pin Header | SW3 | 2Pin-Header-Conn | SW_2Pin_100mil_Switch | 1 | C124375
TL3305AF160QG | Tactile Switch SPST-NO Top Actuated Surface Mount | SW4 | Switch_JLC | SW_Push_Button_JLC | 1 | C2837550
PREC003SAAN-RC | Connector Header Through Hole 3 position 0.100" (2.54mm) | SW5 | 3_PIN_100mil | SW_3Pin_100mil_Switch | 1 | C49257
PREC003SAAN-RC | Connector Header Through Hole 3 position 0.100" (2.54mm) | SW6 | 3_PIN_100mil | SW_3Pin_100mil_Switch | 1 | C49257
10x Probe TP | Test Point 300 mil centers | TP2 | TP10x_Probe | TP_10x_Probe | 1
10x Probe TP | Test Point 300 mil centers | TP18 | TP10x_Probe | TP_10x_Probe | 1
10x Probe TP | Test Point 300 mil centers | TP19 | TP10x_Probe | TP_10x_Probe | 1
10x Probe TP | Test Point 300 mil centers | Tx | TP10x_Probe | TP_10x_Probe | 1
CH340G | Transceiver USB 2.0 2Mbps SOP-16_150mil USB ICs RoHS | U1 | USB to serial | U_USBtoSerial | 1 | C14267
ATMEGA328P-ANR | AVR AVR® ATmega Microcontroller IC 8-Bit 20MHz 32KB (16K x 16) FLASH 32-TQFP (7x7) | U2 | ATMega328P | U_ATMega328P | 1 | C14877
DAC IC | IC DAC 12BIT V-OUT SOT23-6 | U3 | MCP4725 | U_MCP4725A0T-E/CH | 1 | C144198
ADS1115IDGSR | 16-Bit ADC with Integrated MUX, PGA, Comparator, Oscillator, and Reference 10-VSSOP -40 to 125 | U4 | ADC_ADS1115IDGSR | U_ADC_ADS1115IDGSR | 1 | C37593
MCP6002T-I/SN | 0.6 V/us 2 1MHz 1.8V ~ 6V 100μA General Purpose SOIC-8_150mil Operational Amplifier ROHS | U5 | SOIC127P600X175-8N | U_MCP6002T-I/SN | 1 | C7377
10x Probe TP | Test Point 300 mil centers | VRM_hi | TP10x_Probe | TP_10x_Probe | 1
Power Jack | Power Barrel Connector Jack 2.10mm ID (0.083"), 5.50mm OD (0.217") Through Hole, Right Angle | y | Power_Jack | P_Power Jack | 1 | C136744
X322512MSB4SI | SMD Crystal Resonators 12MHz ±10ppm SMD-3225_4P RoHS | Y1 | Crystal resonator | X_12MHz_Res | 1 | C9002
X322516MLB4SI | ±10ppm 16000000Hz -40℃~85℃ 贴片无源晶振 60Ω 9pF SMD3225-4P Crystals ROHS | Y2 | Crystal resonator | X_16Mhz_Res | 1 | C13738

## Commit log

2024-03-13 Golden Arduino and Instrument droid PCB
    [ECEN5730_Instrument droid_Shrinithi_BOM.xlsx, ECEN5730_Intrument_Droid_Shrinithi_PNP.csv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]
2024-03-13 Design Files - Gerber, BOM, PartNames
    [ECEN5730_Instrument droid_Shrinithi_BOM.xlsx, ECEN5730_Intrument_Droid_Shrinithi_PNP.csv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]
